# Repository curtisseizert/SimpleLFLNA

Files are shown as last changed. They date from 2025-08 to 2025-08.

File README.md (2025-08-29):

# SimpleLFLNA

This project contains design files for a low-frequency (0.1 - 10 Hz), AC-coupled low noise amplifier intended for measuring noise of voltage references, low noise linear supplies, etc. A number of other designs utilize input high pass filters with large (1 - 2.2 mF) electrolytic capacitors and low (ca. 1 k) resistors, this approach suffers from several drawbacks. Electrolytic capacitors exhibit high levels of dielectric absorption, leading to long settling times. Leakage can also be problematic and requires selection of parts to ensure that the amplifier does not saturate when DC bias is applied. Moreover, measurements of sources like unbuffered DAC outputs suffers from considerable input signal attenuation due to low input impedance in the passband. This design instead utilizes a much smaller (4.7 uF) polypropylene AC-coupling capacitor and large (10M) resistor with a hybrid JFET input amplifier to remove the DC bias from the signal of interest. Dielectric absorption and leakage for polypropylene capacitors is much lower than that of Al electrolytics, allowing faster settling and obviating part selection.

Simple_LFLNA_3d

While this amplifier is yet to be built and tested, the design concept borrows heavily from another project (https://github.com/curtisseizert/LowFreqLNA). That project was aimed at lowest possible noise and greatest bandwidth, with different gain and bandwidth options accessible via front panel switches, but the resulting complexity, part count, and cost were relatively high for a DIY project. This project is a simpler and less expensive version with fixed gain and bandwidth. The board is a 4-layer 120x78 mm PCB designed to fit in a Hammond 1455K1201 enclosure. The amplifier can be powered by two 9V batteries or an external power source. The "settle" switch, which discharges the interstage HP filter capacitors and saturation indicator are reasonably simple quality of life features that were maintained from the more complex version. The expected noise floor is about 60-75 nV p-p depending upon some parts choices noted in the schematic. BOM cost is ca. $75 from Digikey.

I will update this repository with testing results once I have built a prototype.

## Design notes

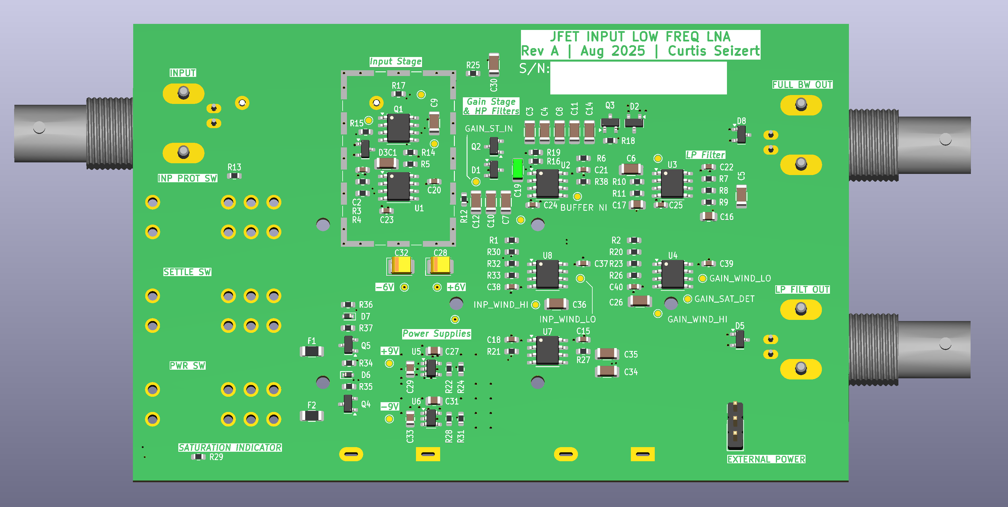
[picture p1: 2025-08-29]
Simple_LFLNA_3d.png

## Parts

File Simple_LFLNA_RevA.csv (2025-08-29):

Reference | Value | Datasheet | Footprint | Qty | DNP | P/N | Digikey Price
BT1,BT2 | Battery | ~ | Battery:BatteryHolder_MPD_BA9VPC_1xPP3 | 2
C1,C9,C19,C26,C30,C36 | 22nF | ~ | Capacitor_SMD:C_1206_3216Metric | 6 |  | GRT3195C2A223JA02D | 0.35
C2,C15,C18,C20,C21,C22,C23,C24,C25,C37,C38,C39,C40 | 0.1uF X7R | ~ | Capacitor_SMD:C_0603_1608Metric | 13 |  | GCJ188R71H104KA12D | 0.072
C3,C4,C5,C6,C7,C8,C10,C11,C12,C14 | 470nF | ~ | Capacitor_SMD:C_1206_3216Metric | 10 |  | GRM31C5C1E474JE01L | 0.429
C13 | 4.7uF PP | ~ | Capacitor_THT:C_Rect_L24.0mm_W10.9mm_P22.50mm_MKT | 1 |  | ECW-FD2W475J | 1.63
C16,C17 | 47nF | ~ | Capacitor_SMD:C_0805_2012Metric | 2 |  | C0805C473K3GECTU | 0.31
C27,C29,C31,C33 | 4.7uF X7R | ~ | Capacitor_SMD:C_0805_2012Metric | 4 |  | GRM21BZ71E475KE15L | 0.25
C28,C32 | 47uF/16V/Ta | ~ | Capacitor_Tantalum_SMD:CP_EIA-3528-21_Kemet-B | 2 |  | TMCMB1C476MTRF | 0.75
C34,C35 | 100nF | ~ | Capacitor_SMD:C_1206_3216Metric | 2 |  | GRM3195C1H104JA05D | 0.35
D1,D2,D3,D5,D8 | BAV199 | https://assets.nexperia.com/documents/data-sheet/BAV99_SER.pdf | Package_TO_SOT_SMD:SOT-23 | 5 |  | BAV199-7-F | 0.07
D4 | LED | ~ | LED_SMD:LED_Dialight_591 | 1 |  | 5912001007NF | 1.98
D6,D7 | EDZVFHT2R15B | https://industrial.panasonic.com/content/data/SC/ds/ds4/DZ2S15000L_E.pdf | Diode_SMD:D_SOD-523 | 2 |  | EDZVFHT2R15B | 0.18
F1,F2 | Polyfuse | ~ | Fuse:Fuse_1206_3216Metric | 2 |  | 0ZCJ0020FF2E | 0.17
J1,J2,J5 | Conn_Coaxial | ~ | Connector_Coaxial:BNC_Amphenol_B6252HB-NPP3G-50_Horizontal | 3 |  | CONBNC002 | 2.05
J3 | RF_Shield_Two_Pieces | ~ | RF_Shielding:Laird_Technologies_BMI-S-209-F_29.36x18.50mm | 1 |  | BMI_S_209
J4 | External Power Connector | ~ | Connector_PinHeader_2.54mm:PinHeader_1x03_P2.54mm_Vertical | 1
Q1 | JFE2140D | https://www.ti.com/lit/ds/symlink/jfe2140.pdf | Package_SO:SOIC-8_3.9x4.9mm_P1.27mm | 1 |  | JFE2140DR | 4.64
Q2,Q3 | MMBF4117 | https://www.mouser.com/datasheet/2/308/1/MMBF4117_D-3150161.pdf | Package_TO_SOT_SMD:SOT-23 | 2 |  | MMBF4117 | 0.56
Q4 | DMN6075S | http://www.diodes.com/assets/Datasheets/DMN6075S.pdf | Package_TO_SOT_SMD:SOT-23 | 1 |  | DMN6075S-7 | 0.34
Q5 | IRLML9301 | https://www.infineon.com/dgdl/irlml9301pbf.pdf?fileId=5546d462533600a401535668e5e42640 | Package_TO_SOT_SMD:SOT-23 | 1 |  | IRLML9301TRPBF | 0.43
R1,R2,R13,R24,R25,R29,R31 | 10k | ~ | Resistor_SMD:R_0603_1608Metric | 7
R3,R4,R17 | 4k02 | ~ | Resistor_SMD:R_0603_1608Metric | 3
R5,R16 | 19k8 0.1% | ~ | Resistor_SMD:R_0603_1608Metric | 2
R6,R7,R38 | 49R9 | ~ | Resistor_SMD:R_0603_1608Metric | 3
R8 | 18k7 | ~ | Resistor_SMD:R_0603_1608Metric | 1
R9,R20,R26,R30,R33 | 604k | ~ | Resistor_SMD:R_0603_1608Metric | 5
R10,R21,R34,R36 | 56k2 | ~ | Resistor_SMD:R_0603_1608Metric | 4
R11 | 200k | ~ | Resistor_SMD:R_0603_1608Metric | 1
R12,R15,R23,R27,R32,R35,R37 | 10M | ~ | Resistor_SMD:R_0603_1608Metric | 7
R14,R19 | 200R 0.1% | ~ | Resistor_SMD:R_0603_1608Metric | 2
R18 | 680k | ~ | Resistor_SMD:R_0603_1608Metric | 1
R22,R28 | 39k | ~ | Resistor_SMD:R_0603_1608Metric | 2
SW1,SW2,SW3 | SW_DPDT_x2 | ~ | Footprints:SW_DPDT_E-Switch_100DP1T2B4M7QE | 3 |  | 100DP1T1B4M7QE | 5.17
TP1,TP2,TP3,TP4,TP5,TP6,TP7,TP8,TP9,TP10,TP11,TP12,TP13,TP14,TP15,TP16,TP17 | TestPoint | ~ | TestPoint:TestPoint_Pad_D1.0mm | 17
U1 | ADA4622-1 | https://www.analog.com/media/en/technical-documentation/data-sheets/ADA4610-1_4610-2_4610-4.pdf | Package_SO:SOIC-8_3.9x4.9mm_P1.27mm | 1 |  | ADA4622-1-ARZ | 5.88
U2,U3 | ADA4622-2 | https://www.analog.com/media/en/technical-documentation/data-sheets/ada4622-1-4622-2-4622-4.pdf | Package_SO:SOIC-8_3.9x4.9mm_P1.27mm | 2 |  | ADA4622-2-ARZ | 8.17
U4,U8 | TLV1822D | http://www.ti.com/lit/ds/symlink/lmv331.pdf | Package_SO:SOIC-8_3.9x4.9mm_P1.27mm | 2 |  | TLV1822DR | 1.89
U5 | LP2980-ADJ | http://www.ti.com/lit/ds/symlink/lp2980-adj.pdf | Package_TO_SOT_SMD:SOT-23-5 | 1 |  | LP2980IM5-ADJ/NOPB | 0.76
U6 | TPS72301DBV | https://www.ti.com/lit/ds/symlink/tps723.pdf | Package_TO_SOT_SMD:SOT-23-5 | 1 |  | TPS72301DBVT | 3.80
U7 | ICM7555IBAZ | http://www.ti.com/lit/ds/symlink/tlc555.pdf | Package_SO:SOIC-8_3.9x4.9mm_P1.27mm | 1 |  | ICM7555IBAZ-T | 0.76

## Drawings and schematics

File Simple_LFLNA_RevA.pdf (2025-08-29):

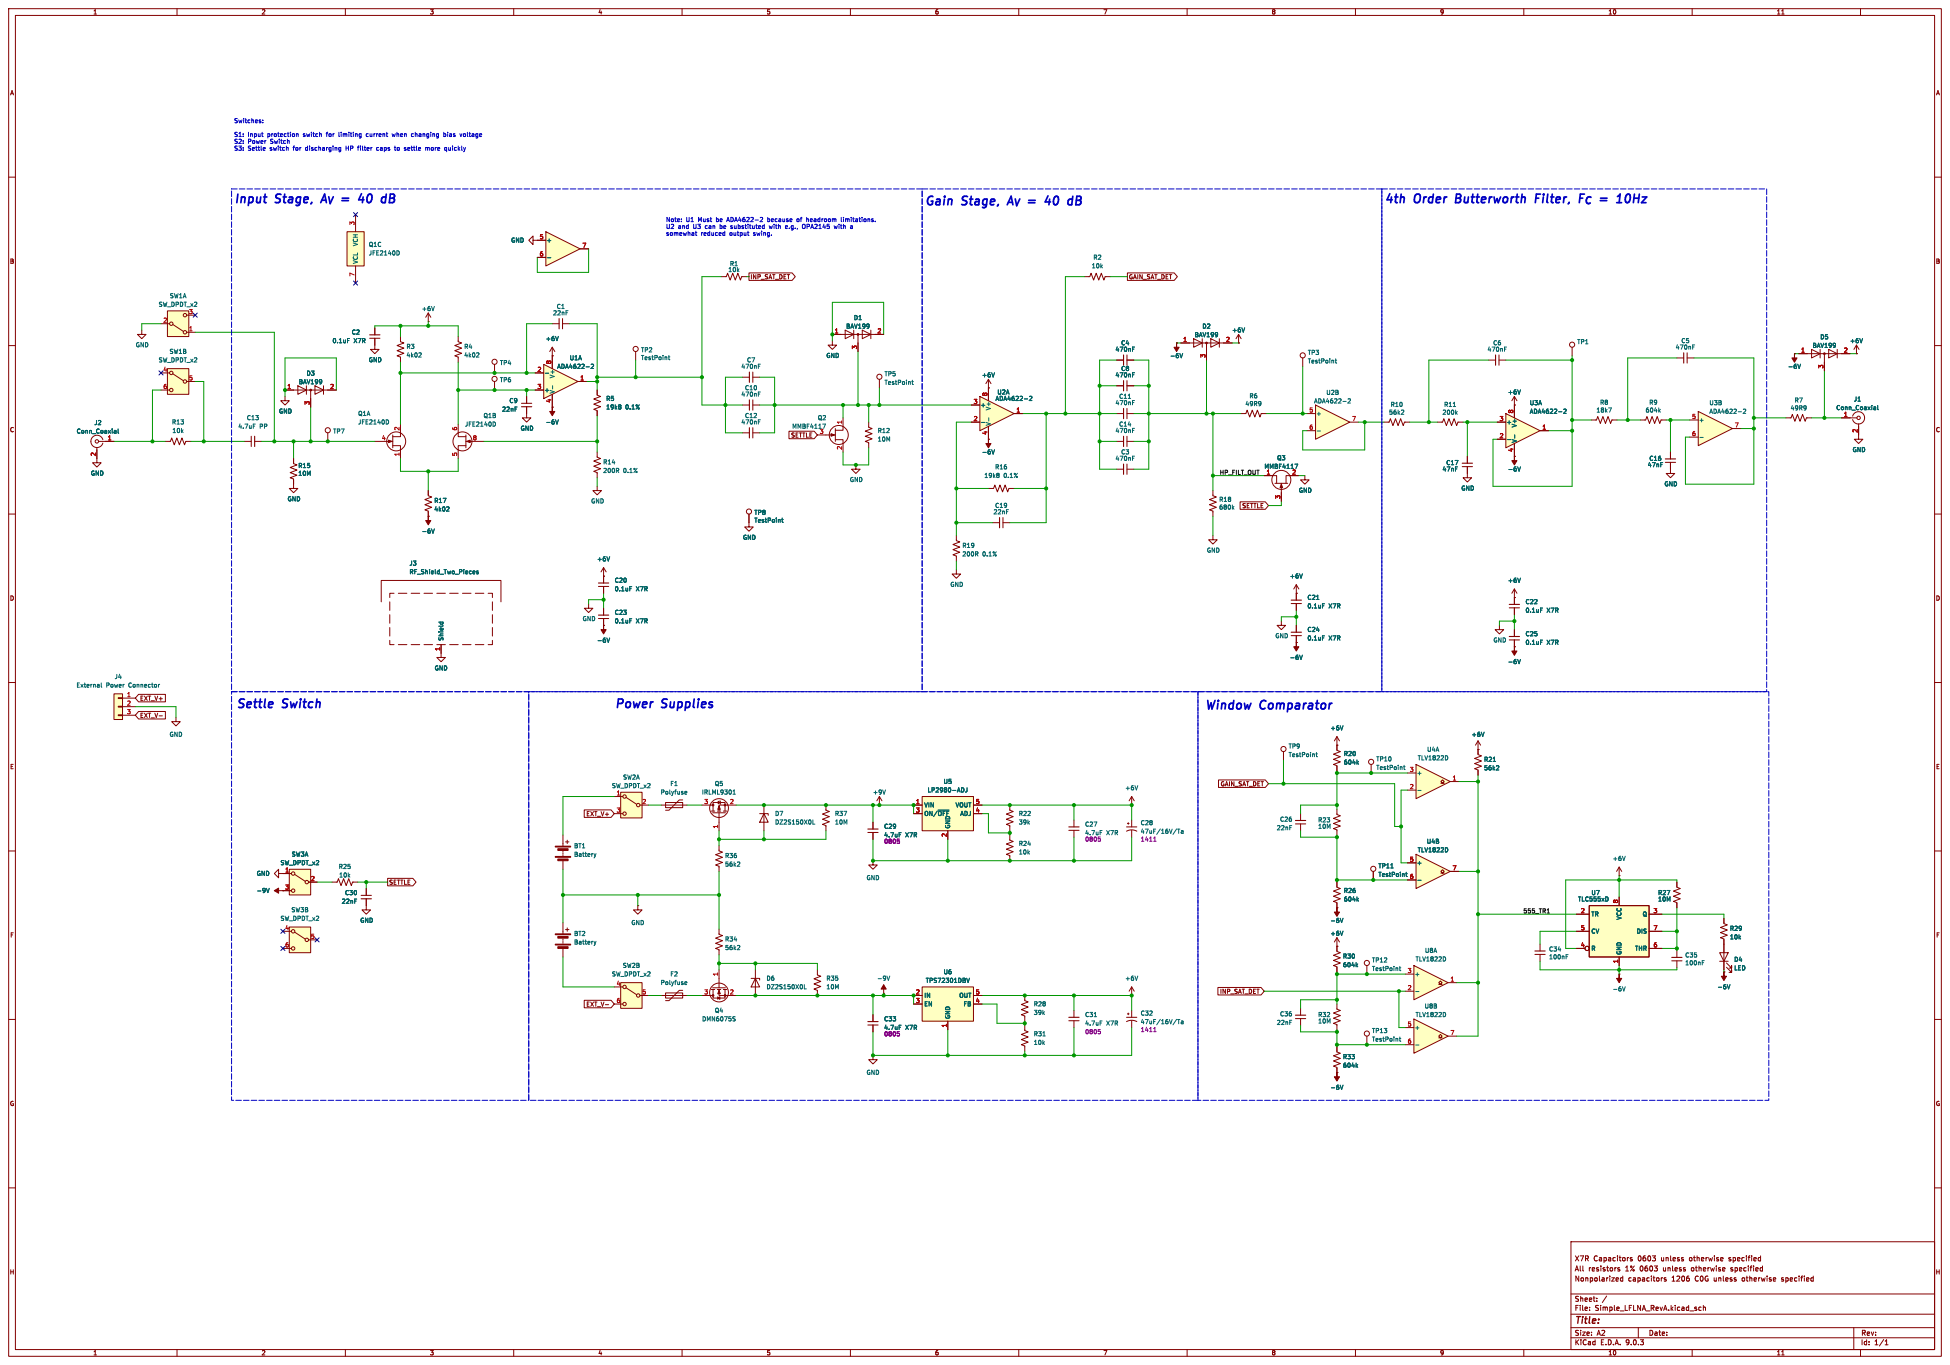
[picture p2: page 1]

somewhat reduced output swing.

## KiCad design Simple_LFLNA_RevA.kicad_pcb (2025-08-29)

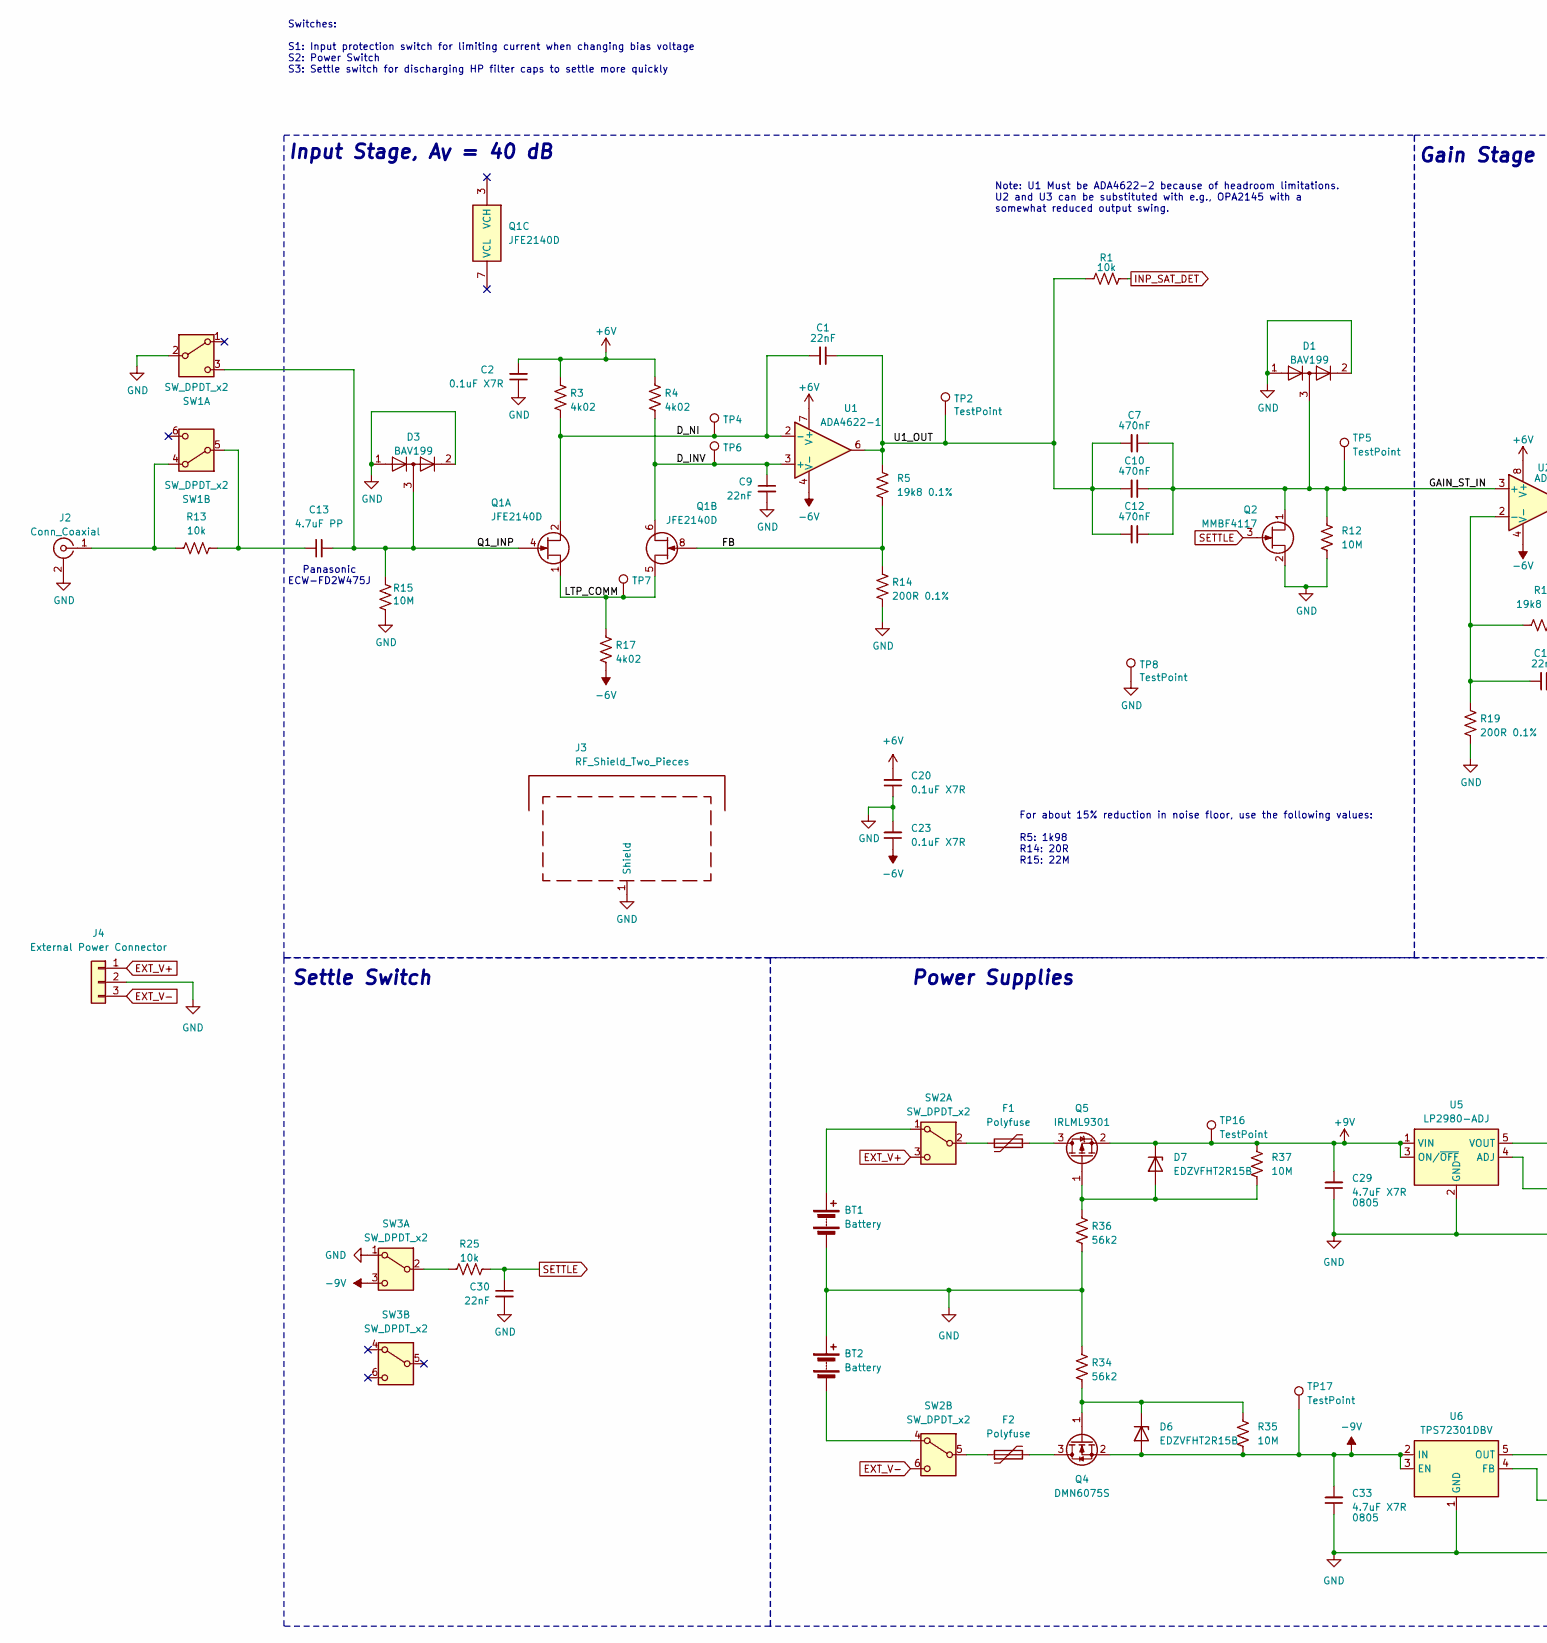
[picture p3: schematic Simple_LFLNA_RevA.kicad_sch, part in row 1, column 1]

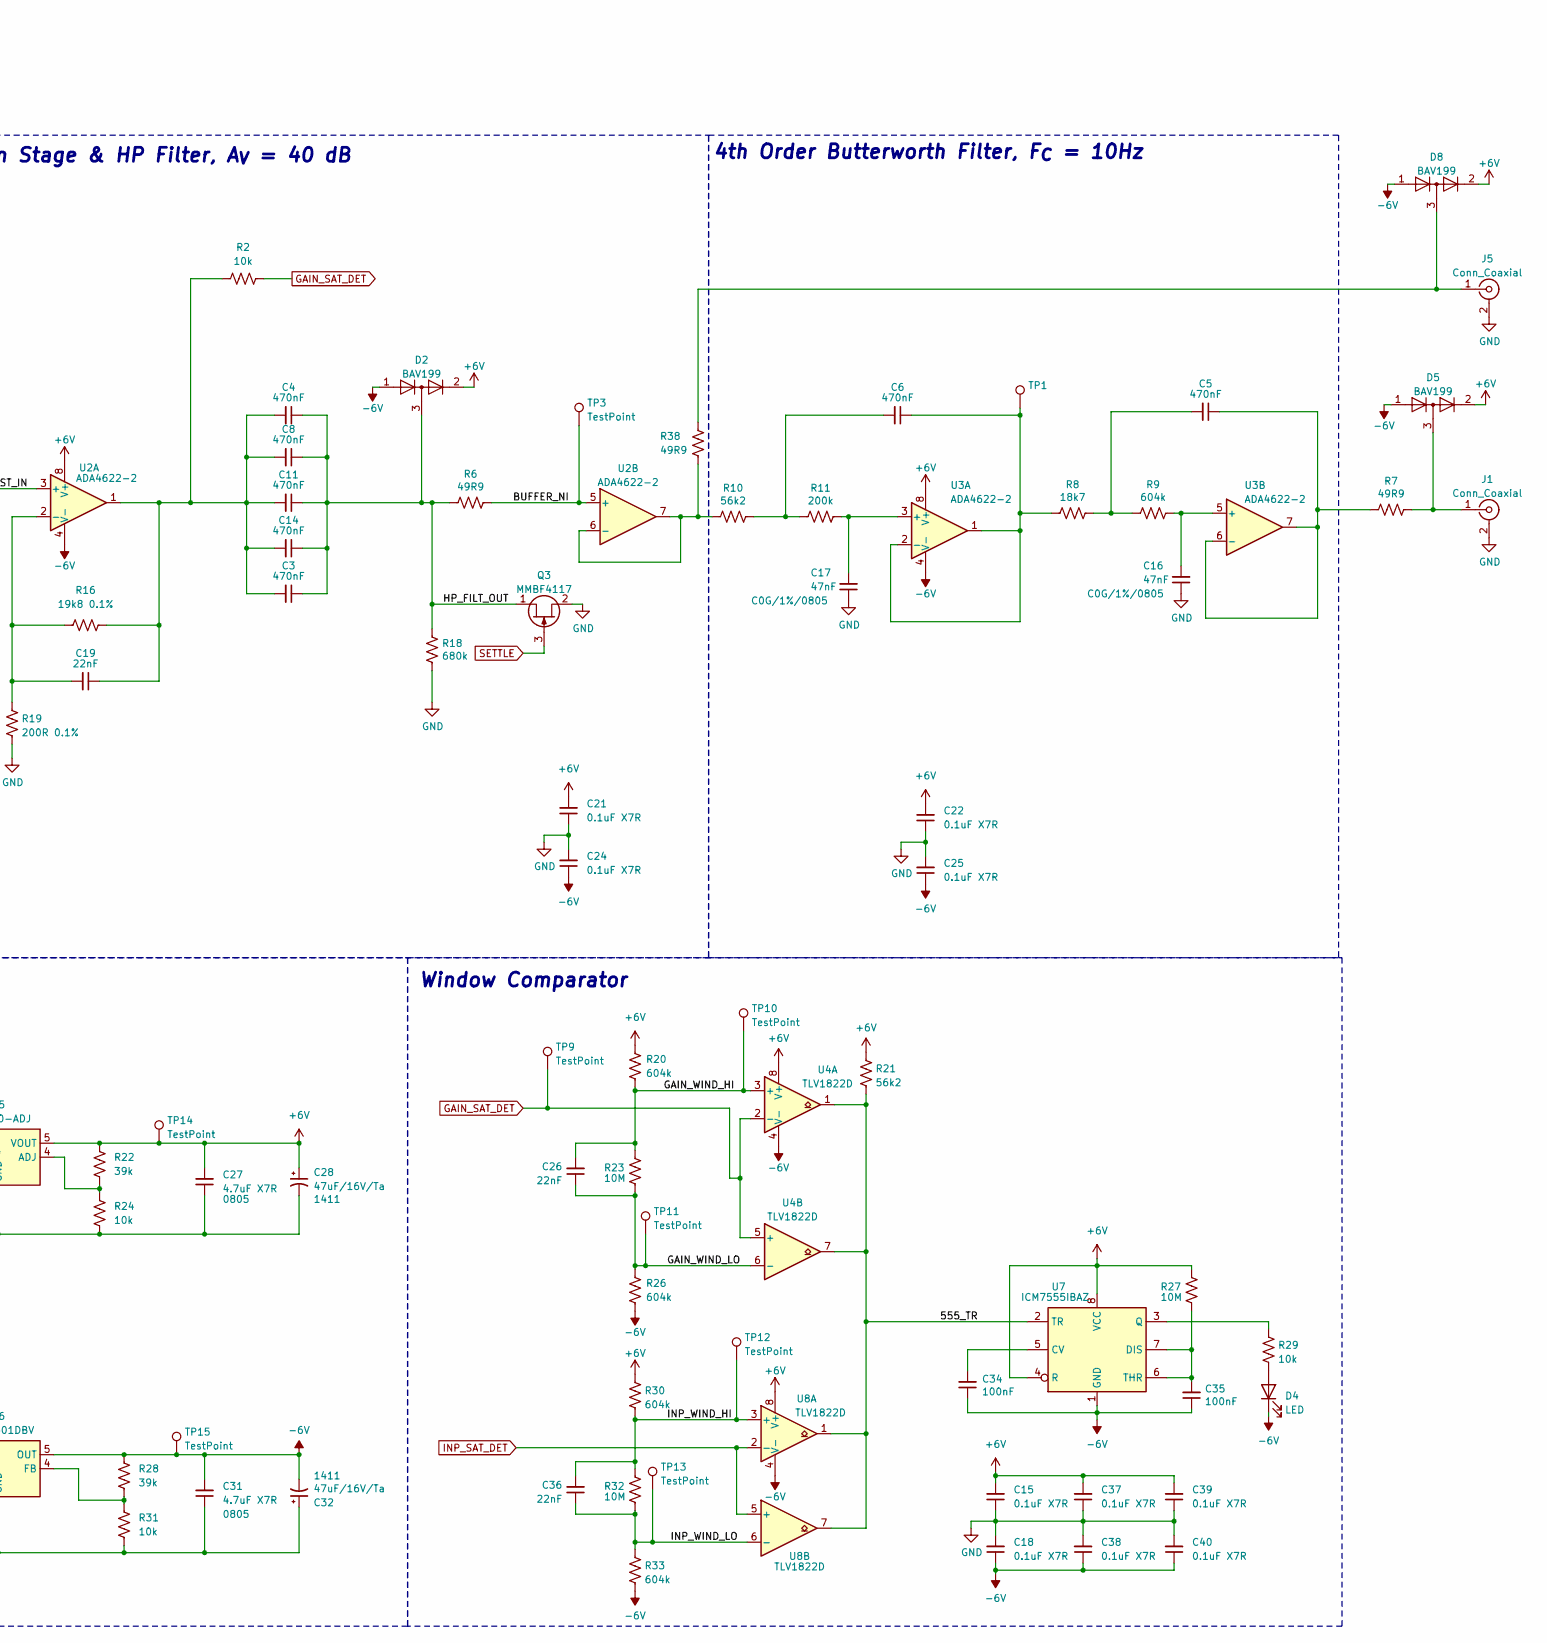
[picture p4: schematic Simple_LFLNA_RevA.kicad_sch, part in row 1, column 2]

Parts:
BT1, BT2: Battery; BatteryHolder_MPD_BA9VPC_1xPP3; Digikey Price 2.42
C1, C9, C19, C26, C30, C36: 22nF; C_1206_3216Metric; Digikey Price 0.35
C2, C15, C18, C20, C21, C22, C23, C24, C25, C37, C38, C39, C40: 0.1uF X7R; C_0603_1608Metric; Digikey Price 0.072
C3, C4, C5, C6, C7, C8, C10, C11, C12, C14: 470nF; C_1206_3216Metric; Digikey Price 0.429
C13: 4.7uF PP; C_Rect_L24.0mm_W10.9mm_P22.50mm_MKT; Digikey Price 1.63
C16, C17: 47nF; C_0805_2012Metric; Digikey Price 0.31
C27, C29, C31, C33: 4.7uF X7R; C_0805_2012Metric; Digikey Price 0.25
C28, C32: 47uF/16V/Ta; CP_EIA-3528-21_Kemet-B; Digikey Price 0.75
C34, C35: 100nF; C_1206_3216Metric; Digikey Price 0.35
D1, D2, D3, D5, D8: BAV199; SOT-23; Digikey Price 0.07
D4: LED; LED_Dialight_591; Digikey Price 1.98
D6, D7: EDZVFHT2R15B; D_SOD-523; Digikey Price 0.18
F1, F2: Polyfuse; Fuse_1206_3216Metric; Digikey Price 0.17
J1, J2, J5: Conn_Coaxial; BNC_Amphenol_B6252HB-NPP3G-50_Horizontal; Digikey Price 2.05
J3: RF_Shield_Two_Pieces; Laird_Technologies_BMI-S-209-F_29.36x18.50mm; Mouser P/N 739-BMI-S-206-F
J4: External Power Connector; PinHeader_1x03_P2.54mm_Vertical
Q1: JFE2140D; SOIC-8_3.9x4.9mm_P1.27mm; Digikey Price 4.64
Q2, Q3: MMBF4117; SOT-23; Digikey Price 0.56
Q4: DMN6075S; SOT-23; Digikey Price 0.34
Q5: IRLML9301; SOT-23; Digikey Price 0.43
R1, R2, R13, R24, R25, R29, R31: 10k; R_0603_1608Metric
R3, R4, R17: 4k02; R_0603_1608Metric
R5, R16: 19k8 0.1%; R_0603_1608Metric
R6, R7, R38: 49R9; R_0603_1608Metric
R8: 18k7; R_0603_1608Metric; Mouser P/N 754-RR0816P-1872D27C
R9: 604k; R_0603_1608Metric; Mouser P/N 603-RT0603DRE07604KL
R10, R21, R34, R36: 56k2; R_0603_1608Metric; Mouser P/N 754-RR0816P-5622D73C
R11: 200k; R_0603_1608Metric; Mouser P/N 754-RR0816P-204D
R12, R15, R23, R27, R32, R35, R37: 10M; R_0603_1608Metric
R14, R19: 200R 0.1%; R_0603_1608Metric
R18: 680k; R_0603_1608Metric
R20, R26, R30, R33: 604k; R_0603_1608Metric
R22, R28: 39k; R_0603_1608Metric
SW1, SW2, SW3: SW_DPDT_x2; SW_DPDT_E-Switch_100DP1T2B4M7QE; Digikey Price 5.17
TP1, TP2, TP3, TP4, TP5, TP6, TP7, TP8, TP9, TP10, TP11, TP12, TP13, TP14, TP15, TP16, TP17: TestPoint; TestPoint_Pad_D1.0mm
U1: ADA4622-1; SOIC-8_3.9x4.9mm_P1.27mm; Digikey Price 5.88
U2, U3: ADA4622-2; SOIC-8_3.9x4.9mm_P1.27mm; Digikey Price 8.17
U4, U8: TLV1822D; SOIC-8_3.9x4.9mm_P1.27mm; Digikey Price 1.89
U5: LP2980-ADJ; SOT-23-5; Digikey Price 0.76
U6: TPS72301DBV; SOT-23-5; Digikey Price 3.80
U7: ICM7555IBAZ; SOIC-8_3.9x4.9mm_P1.27mm; Mouser P/N 700-ICM7555ISAT

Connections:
+6V: C2.2, C15.2, C20.2, C21.2, C22.2, C27.2, C28.1, C37.2, C39.2, D2.2 (A), D5.2 (A), D8.2 (A), R3.1, R4.1, R20.1, R21.1, R22.2, R27.1, R30.1, TP14.1, U1.7 (V+), U2.8 (V+), U3.8 (V+), U4.8 (V+), U5.5 (VOUT), U7.4 (R), U7.8 (VCC), U8.8 (V+)
+9V: C29.2, D7.1 (K), Q5.2 (S), R37.1, TP16.1, U5.1 (VIN), U5.3 (ON/~OFF)
-6V: C18.1, C23.1, C24.1, C25.1, C31.2, C32.2, C34.1, C35.1, C38.1, C40.1, D2.1 (K), D4.1 (K), D5.1 (K), D8.1 (K), R17.2, R26.2, R28.2, R33.2, TP15.1, U1.4 (V-), U2.4 (V-), U3.4 (V-), U4.4 (V-), U6.5 (OUT), U7.1 (GND), U8.4 (V-)
-9V: C33.2, D6.2 (A), Q4.2 (S), R35.2, SW3.3 (C), TP17.1, U6.2 (IN), U6.3 (EN)
/555_TR: R21.2, U4.1, U4.7, U7.2 (TR), U8.1, U8.7
/BUFFER_NI: R6.1, TP3.1, U2.5 (+)
/D_INV: C9.1, Q1.6, R4.2, TP6.1, U1.3 (+)
/D_NI: C1.2, Q1.2, R3.2, TP4.1, U1.2 (-)
/FB: Q1.8, R5.1, R14.1
/GAIN_ST_IN: C7.1, C10.1, C12.1, D1.3 (K), Q2.1 (D), R12.1, TP5.1, U2.3 (+)
/GAIN_WIND_HI: C26.2, R20.2, R23.1, TP10.1, U4.3 (+)
/GAIN_WIND_LO: C26.1, R23.2, R26.1, TP11.1, U4.6 (-)
/HP_FILT_OUT: C3.1, C4.1, C8.1, C11.1, C14.1, D2.3 (K), Q3.1 (D), R6.2, R18.1
/INP_WIND_HI: C36.2, R30.2, R32.1, TP12.1, U8.3 (+)
/INP_WIND_LO: C36.1, R32.2, R33.1, TP13.1, U8.6 (-)
/LTP_COMM: Q1.1, Q1.5, R17.1, TP7.1
/Q1_INP: C13.2, D3.3 (K), Q1.4, R15.1, SW1.3 (C)
/U1_OUT: C1.1, C7.2, C10.2, C12.2, R1.1, R5.2, TP2.1, U1.6
EXT_V+: J4.1, SW2.3 (C)
EXT_V-: J4.3, SW2.6 (C)
GAIN_SAT_DET: R2.2, TP9.1, U4.2 (-), U4.5 (+)
GND: BT1.2 (-), BT2.1 (+), C2.1, C9.2, C15.1, C16.1, C17.1, C18.2, C20.1, C21.1, C22.1, C23.2, C24.2, C25.2, C27.1, C28.2, C29.1, C30.2, C31.1, C32.1, C33.1, C37.1, C38.2, C39.1, C40.2, D1.1 (K), D1.2 (A), D3.1 (K), D3.2 (A), J1.2 (Ext), J2.2 (Ext), J3.1 (Shield), J4.2, J5.2 (Ext), Q2.2 (S), Q3.2 (S), R12.2, R14.2, R15.2, R18.2, R19.2, R24.2, R31.2, R34.1, R36.2, SW1.2 (B), SW3.1 (A), TP8.1, U5.2 (GND), U6.1 (GND)
INP_SAT_DET: R1.2, U8.2 (-), U8.5 (+)
unnamed: BT1.1 (+), SW2.1 (A)
unnamed: BT2.2 (-), SW2.4 (A)
unnamed: C5.2, R8.1, R9.2
unnamed: C6.2, R10.1, R11.2
unnamed: C3.2, C4.2, C8.2, C11.2, C14.2, C19.1, R2.1, R16.2, U2.1
unnamed: D4.2 (A), R29.2
unnamed: D6.1 (K), Q4.1 (G), R34.2, R35.1
unnamed: D7.2 (A), Q5.1 (G), R36.1, R37.2
unnamed: D5.3 (K), J1.1 (In), R7.1
unnamed: J2.1 (In), R13.1, SW1.4 (A)
unnamed: D8.3 (K), J5.1 (In), R38.1
unnamed: F2.2, Q4.3 (D)
unnamed: F1.2, Q5.3 (D)
unnamed: C13.1, R13.2, SW1.5 (B)
unnamed: F1.1, SW2.2 (B)
unnamed: F2.1, SW2.5 (B)
unnamed: R25.1, SW3.2 (B)
unnamed: C19.2, R16.1, R19.1, U2.2 (-)
unnamed: R10.2, R38.2, U2.6 (-), U2.7
unnamed: C17.2, R11.1, U3.3 (+)
unnamed: C6.1, R8.2, TP1.1, U3.1, U3.2 (-)
unnamed: C16.2, R9.1, U3.5 (+)
unnamed: C5.1, R7.2, U3.6 (-), U3.7
unnamed: R22.1, R24.1, U5.4 (ADJ)
unnamed: R28.1, R31.1, U6.4 (FB)
unnamed: C34.2, U7.5 (CV)
unnamed: C35.2, R27.2, U7.6 (THR), U7.7 (DIS)
unnamed: R29.1, U7.3 (Q)
SETTLE: C30.1, Q2.3 (G), Q3.3 (G), R25.2

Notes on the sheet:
Panasonic ECW-FD2W475J
Input Stage, A_{V} = 40 dB
Switches: S1: Input protection switch for limiting current when changing bias voltage S2: Power Switch S3: Settle switch for discharging HP filter caps to settle more quickly
For about 15% reduction in noise floor, use the following values: R5: 1k98 R14: 20R R15: 22M
Power Supplies
4th Order Butterworth Filter, F_{C} = 10Hz
Note: U1 Must be ADA4622-2 because of headroom limitations. U2 and U3 can be substituted with e.g., OPA2145 with a somewhat reduced output swing.
Window Comparator
Settle Switch
Gain Stage & HP Filter, A_{V} = 40 dB

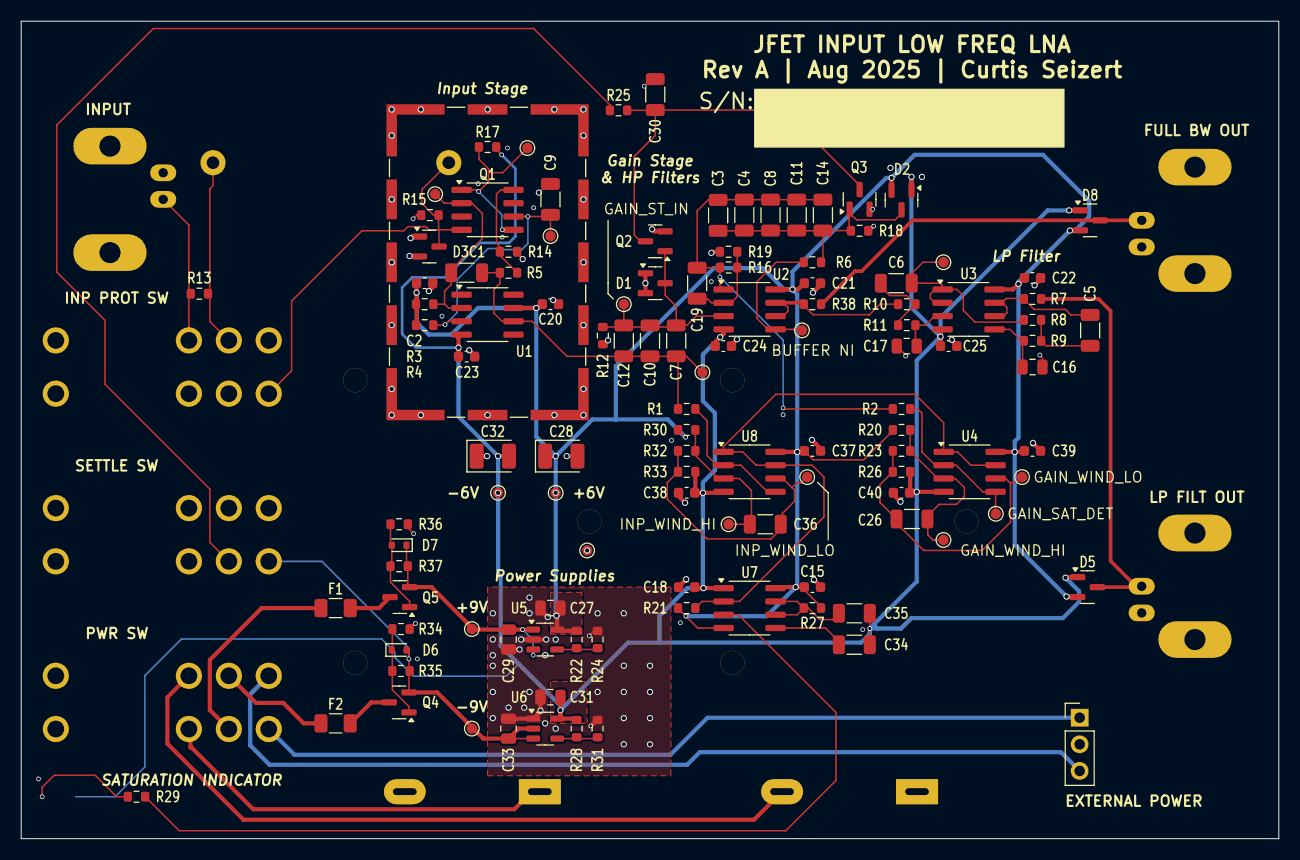
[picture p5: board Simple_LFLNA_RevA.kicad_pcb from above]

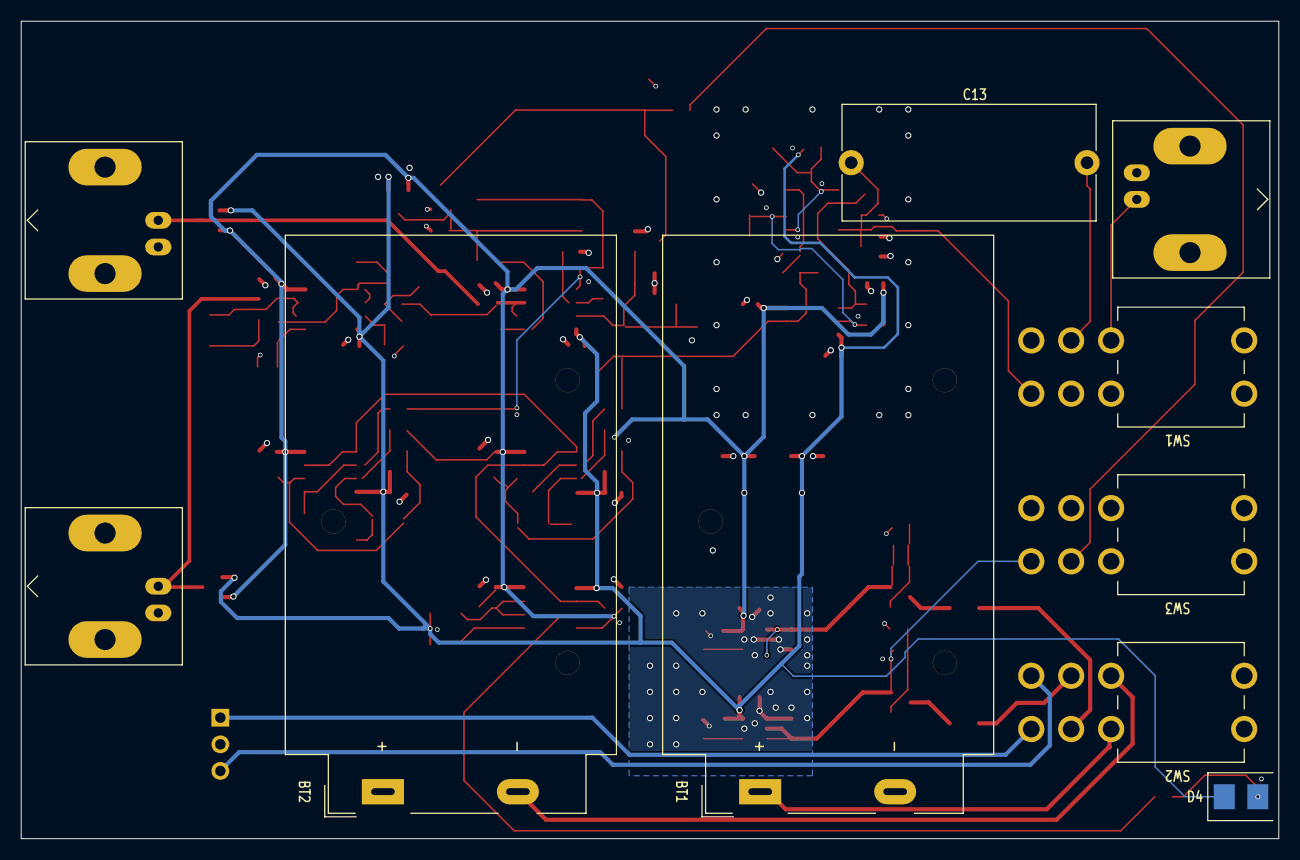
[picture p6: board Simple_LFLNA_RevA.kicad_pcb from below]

Board: 4 copper layers, 120.0 x 78.0 mm, 128 parts (10 on the bottom side), 52 nets.
